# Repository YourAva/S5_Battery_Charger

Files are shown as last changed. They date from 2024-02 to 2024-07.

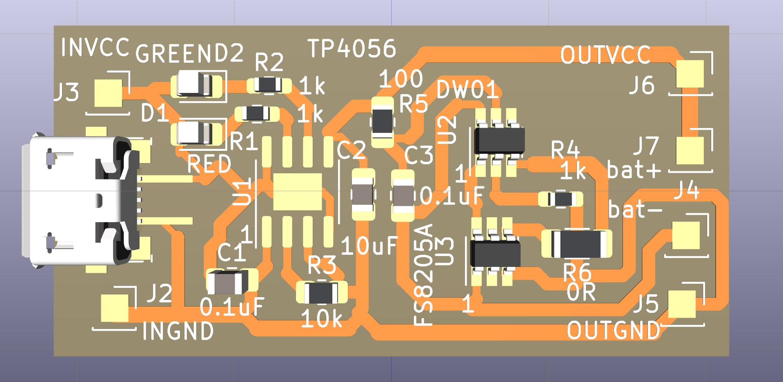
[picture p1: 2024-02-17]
out/tp4056_pcb.jpg

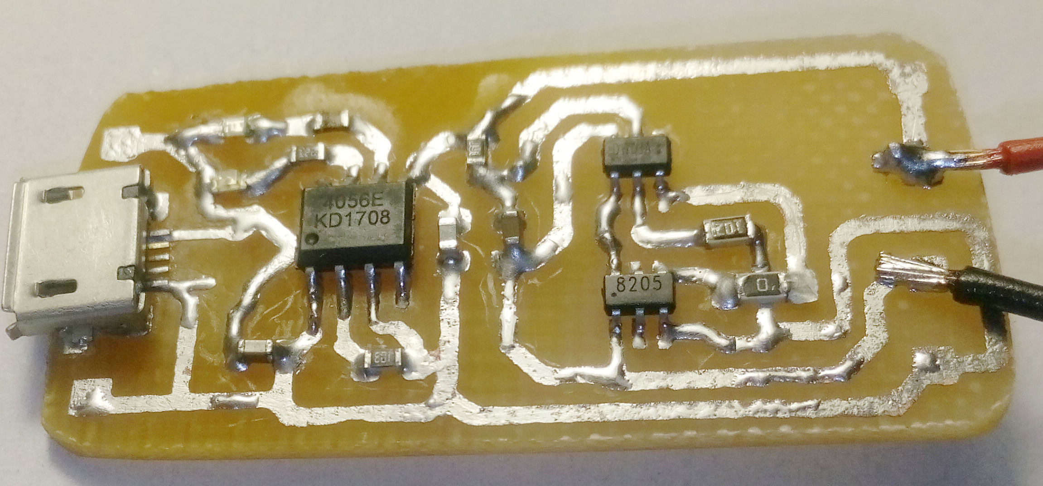
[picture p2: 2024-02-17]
out/tp4056_diy_img2.jpg

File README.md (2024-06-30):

# S5 BATTERY CHARGER

### IMPORTANT

This project is built ontop of another individual's TP4056 board. If you wish to give your respects to the original dev, you can find their github repo that it was pulled from **[here](https://github.com/alltheworld/tp4056)**, any visits to their repo would be greatly appreciated, making sure we all work together is important! >:L

**THE FILE STRUCTURE FOR THIS PROJECT IS DOOKIE RIGHT NOW, I MIGHT FIX IT ONE DAY, BUT AS OF RIGHT NOW IT'S GONE THROUGH 8 DIFFERENT INSTALLS OF WINDOWS AND LINUX AND MULTIPLE KICAD VERSIONS BECAUSE I'M DUMB, LY!**

### Project Overview

This project was made with a pretty simple goal in mind, charging support for the S5 battery, with other options towards charging it and being able to implement it with other circuits, the project provides multiple breakout points so it can adapt to all conditions you'd ever want it to, along with the **SUPERIOR USB-C LINK!!!** ;)

## Credits -- *(thank you all :L )*
- [Original Repo](https://github.com/alltheworld/tp4056)
- [0xArya/@FairywrenTech](https://twitter.com/FairywrenTech)

## Screenshots / Renders







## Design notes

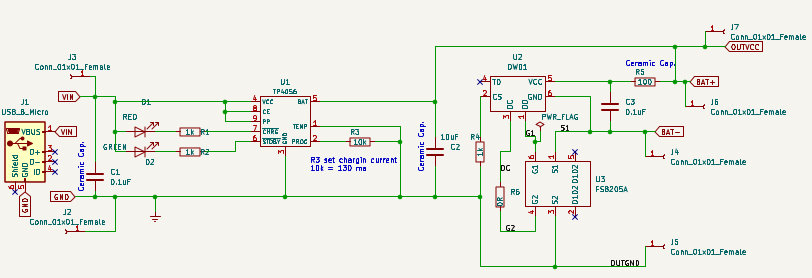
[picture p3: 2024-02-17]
out/tp4056_schematics.jpg

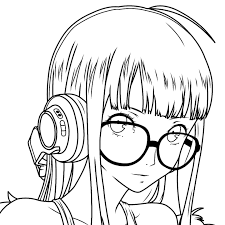
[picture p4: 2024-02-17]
FUtaba.png

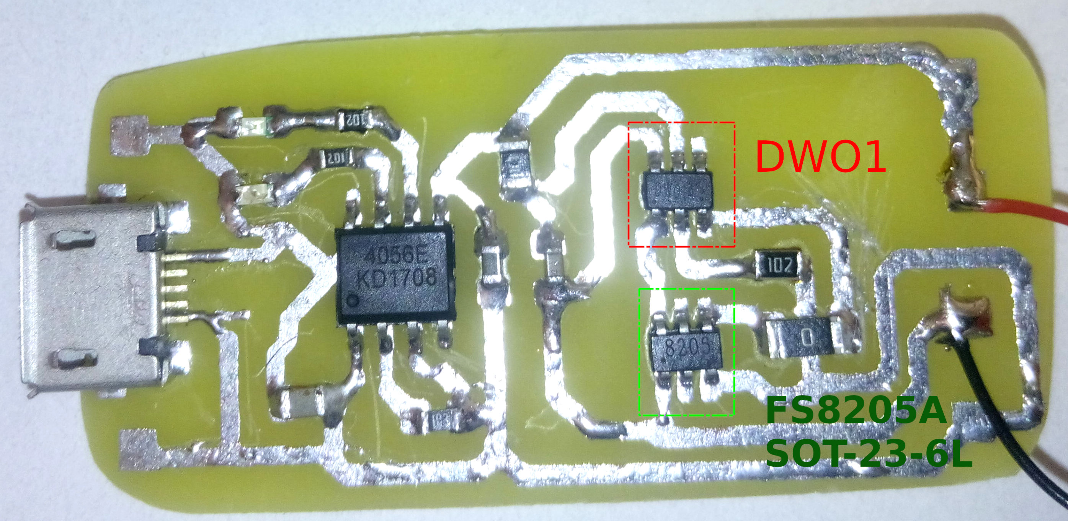
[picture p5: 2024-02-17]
out/tp4056_diy_img1.jpg

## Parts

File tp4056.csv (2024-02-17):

Source: | /data/repo.mbed/tp4056/tp4056_kicad6_base/tp4056.kicad_sch
Date: | Tue 29 Mar 2022 10:57:33 AM EEST
Tool: | Eeschema 6.0.4-6f826c9f35~116~ubuntu20.04.1
Generator: | /usr/share/kicad/plugins/bom_csv_grouped_by_value.py
Component Count: | 21
Individual Components:
Item | Qty | Reference(s) | Value | LibPart | Footprint | Datasheet
 |  | C1 | 0.1uF | Device:C | Capacitor_SMD:C_0805_2012Metric_Pad1.18x1.45mm_HandSolder | ~
 |  | C2 | 10uF | Device:C | Capacitor_SMD:C_0805_2012Metric_Pad1.18x1.45mm_HandSolder | ~
 |  | C3 | 0.1uF | Device:C | Capacitor_SMD:C_0805_2012Metric_Pad1.18x1.45mm_HandSolder | ~
 |  | D1 | LED | Device:LED | LED_SMD:LED_0805_2012Metric_Pad1.15x1.40mm_HandSolder | ~
 |  | D2 | ~ | Device:LED | LED_SMD:LED_0805_2012Metric_Pad1.15x1.40mm_HandSolder | ~
 |  | J1 | USB_B_Micro | Connector:USB_B_Micro | usb_footprint:tp4056_USB_Micro-B_Molex_47346-0001_fix | ~
 |  | J2 | Conn_01x01_Female | Connector:Conn_01x01_Female | Connector_PinSocket_2.54mm:PinSocket_1x01_P2.54mm_Vertical | ~
 |  | J3 | Conn_01x01_Female | Connector:Conn_01x01_Female | Connector_PinSocket_2.54mm:PinSocket_1x01_P2.54mm_Vertical | ~
 |  | J4 | Conn_01x01_Female | Connector:Conn_01x01_Female | Connector_PinSocket_2.54mm:PinSocket_1x01_P2.54mm_Vertical | ~
 |  | J5 | Conn_01x01_Female | Connector:Conn_01x01_Female | Connector_PinSocket_2.54mm:PinSocket_1x01_P2.54mm_Vertical | ~
 |  | J6 | Conn_01x01_Female | Connector:Conn_01x01_Female | Connector_PinSocket_2.54mm:PinSocket_1x01_P2.54mm_Vertical | ~
 |  | J7 | Conn_01x01_Female | Connector:Conn_01x01_Female | Connector_PinSocket_2.54mm:PinSocket_1x01_P2.54mm_Vertical | ~
 |  | R1 | 1k | Device:R | Resistor_SMD:R_0603_1608Metric_Pad0.98x0.95mm_HandSolder | ~
 |  | R2 | 1k | Device:R | Resistor_SMD:R_0603_1608Metric_Pad0.98x0.95mm_HandSolder | ~
 |  | R3 | 10k | Device:R | Resistor_SMD:R_0805_2012Metric_Pad1.20x1.40mm_HandSolder | ~
 |  | R4 | 1k | Device:R | Resistor_SMD:R_0603_1608Metric_Pad0.98x0.95mm_HandSolder | ~
 |  | R5 | 100 | Device:R | Resistor_SMD:R_0805_2012Metric_Pad1.20x1.40mm_HandSolder | ~
 |  | R6 | ZERO | Device:R | Resistor_SMD:R_1206_3216Metric_Pad1.30x1.75mm_HandSolder | ~
 |  | U1 | TP4056 | tp4056:TP4056 | Package_SO:SOIC-8-1EP_3.9x4.9mm_P1.27mm_EP2.29x3mm
 |  | U2 | DW01 | dw01:DW01 | Package_TO_SOT_SMD:SOT-23-6_Handsoldering
 |  | U3 | FS8205A | fs8205:FS8205A | Package_TO_SOT_SMD:SOT-23-6_Handsoldering
Collated Components:
Item | Qty | Reference(s) | Value | LibPart | Footprint | Datasheet
1 | 2 | C1, C3 | 0.1uF | Device:C | Capacitor_SMD:C_0805_2012Metric_Pad1.18x1.45mm_HandSolder | ~
2 | 1 | C2 | 10uF | Device:C | Capacitor_SMD:C_0805_2012Metric_Pad1.18x1.45mm_HandSolder | ~
3 | 1 | D1 | LED | Device:LED | LED_SMD:LED_0805_2012Metric_Pad1.15x1.40mm_HandSolder | ~
4 | 1 | D2 | ~ | Device:LED | LED_SMD:LED_0805_2012Metric_Pad1.15x1.40mm_HandSolder | ~
5 | 1 | J1 | USB_B_Micro | Connector:USB_B_Micro | usb_footprint:tp4056_USB_Micro-B_Molex_47346-0001_fix | ~
6 | 6 | J2, J3, J4, J5, J6, J7 | Conn_01x01_Female | Connector:Conn_01x01_Female | Connector_PinSocket_2.54mm:PinSocket_1x01_P2.54mm_Vertical | ~
7 | 3 | R1, R2, R4 | 1k | Device:R | Resistor_SMD:R_0603_1608Metric_Pad0.98x0.95mm_HandSolder | ~
8 | 1 | R3 | 10k | Device:R | Resistor_SMD:R_0805_2012Metric_Pad1.20x1.40mm_HandSolder | ~
9 | 1 | R5 | 100 | Device:R | Resistor_SMD:R_0805_2012Metric_Pad1.20x1.40mm_HandSolder | ~
10 | 1 | R6 | ZERO | Device:R | Resistor_SMD:R_1206_3216Metric_Pad1.30x1.75mm_HandSolder | ~
11 | 1 | U1 | TP4056 | tp4056:TP4056 | Package_SO:SOIC-8-1EP_3.9x4.9mm_P1.27mm_EP2.29x3mm
12 | 1 | U2 | DW01 | dw01:DW01 | Package_TO_SOT_SMD:SOT-23-6_Handsoldering
13 | 1 | U3 | FS8205A | fs8205:FS8205A | Package_TO_SOT_SMD:SOT-23-6_Handsoldering

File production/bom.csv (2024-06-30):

Designator | Footprint | Quantity | Value | LCSC Part #
C1, C3 | 0603 | 2 | 0.1uF
C2 | 0603 | 1 | 10uF
D1 | 0805 | 1 | RED
D2 | 0805 | 1 | GREEN
J1 | PinHeader_1x01_P2.54mm_Vertical | 1 | Conn_01x01_Pin
J2, J3, J4, J5, J7 | PinSocket_1x01_P2.54mm_Vertical | 5 | Conn_01x01_Female
J6 | CONN-SMD_BC-4-3PD | 1 | Conn_01x03_MountingPin
J8 | USB_C_Receptacle_HRO_TYPE-C-31-M-12 | 1 | USB_C_Receptacle_USB2.0
R1, R2, R4 | 0603 | 3 | 1k
R10 | 0805 | 1 | 1k
R3, R8, R9 | 0603 | 3 | 10k
R5 | 0603 | 1 | 100
R6, R7 | 0603 | 2 | 5.1k
U1 | SOIC-8-1EP_3.9x4.9mm_P1.27mm_EP2.29x3mm | 1 | TP4056
U2 | SOT-23-6_Handsoldering | 1 | DW01
U3 | SOT-23-6_Handsoldering | 1 | FS8205A

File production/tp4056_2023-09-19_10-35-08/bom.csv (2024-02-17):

Designator | Footprint | Quantity | Value | LCSC Part #
C1, C3 | 0805 | 2 | 0.1uF
C2 | 0805 | 1 | 10uF
D1 | 0805 | 1 | RED
D2 | 0805 | 1 | GREEN
J1, J2, J3, J4, J5, J7, J9 | PinSocket_1x01_P2.54mm_Vertical | 7 | Conn_01x01_Female
J6 | CONN-SMD_BC-4-3PD | 1 | Conn_01x03_MountingPin
J8 | USB_C_Receptacle_HRO_TYPE-C-31-M-12 | 1 | USB_C_Receptacle_USB2.0
R1, R2, R4 | 0603 | 3 | 1k
R3 | 0805 | 1 | 10k
R5 | 0805 | 1 | 100
R6, R7 | 0603 | 2 | 5.1k
U1 | SOIC-8-1EP_3.9x4.9mm_P1.27mm_EP2.29x3mm | 1 | TP4056
U2 | SOT-23-6_Handsoldering | 1 | DW01
U3 | SOT-23-6_Handsoldering | 1 | FS8205A

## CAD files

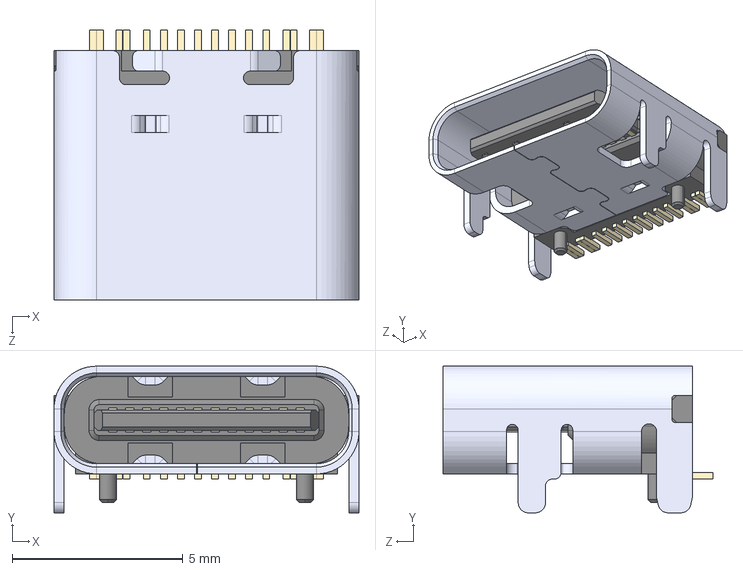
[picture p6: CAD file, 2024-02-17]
TYPE-C-31-M-12--3DModel-STEP-56544.STEP
8.94 x 4.30 x 7.90 mm

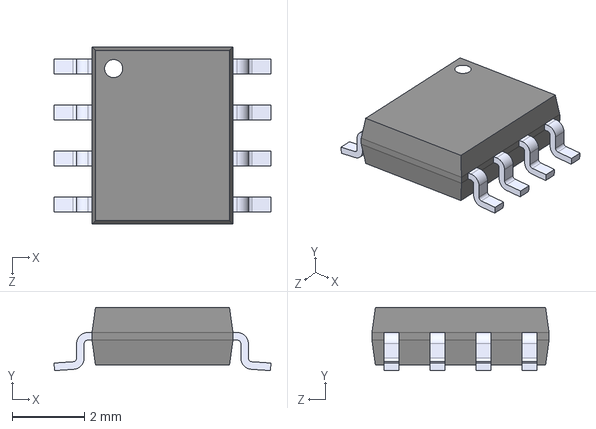
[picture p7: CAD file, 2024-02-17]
TP4056--3DModel-STEP-56544.STEP
6.00 x 1.75 x 4.90 mm

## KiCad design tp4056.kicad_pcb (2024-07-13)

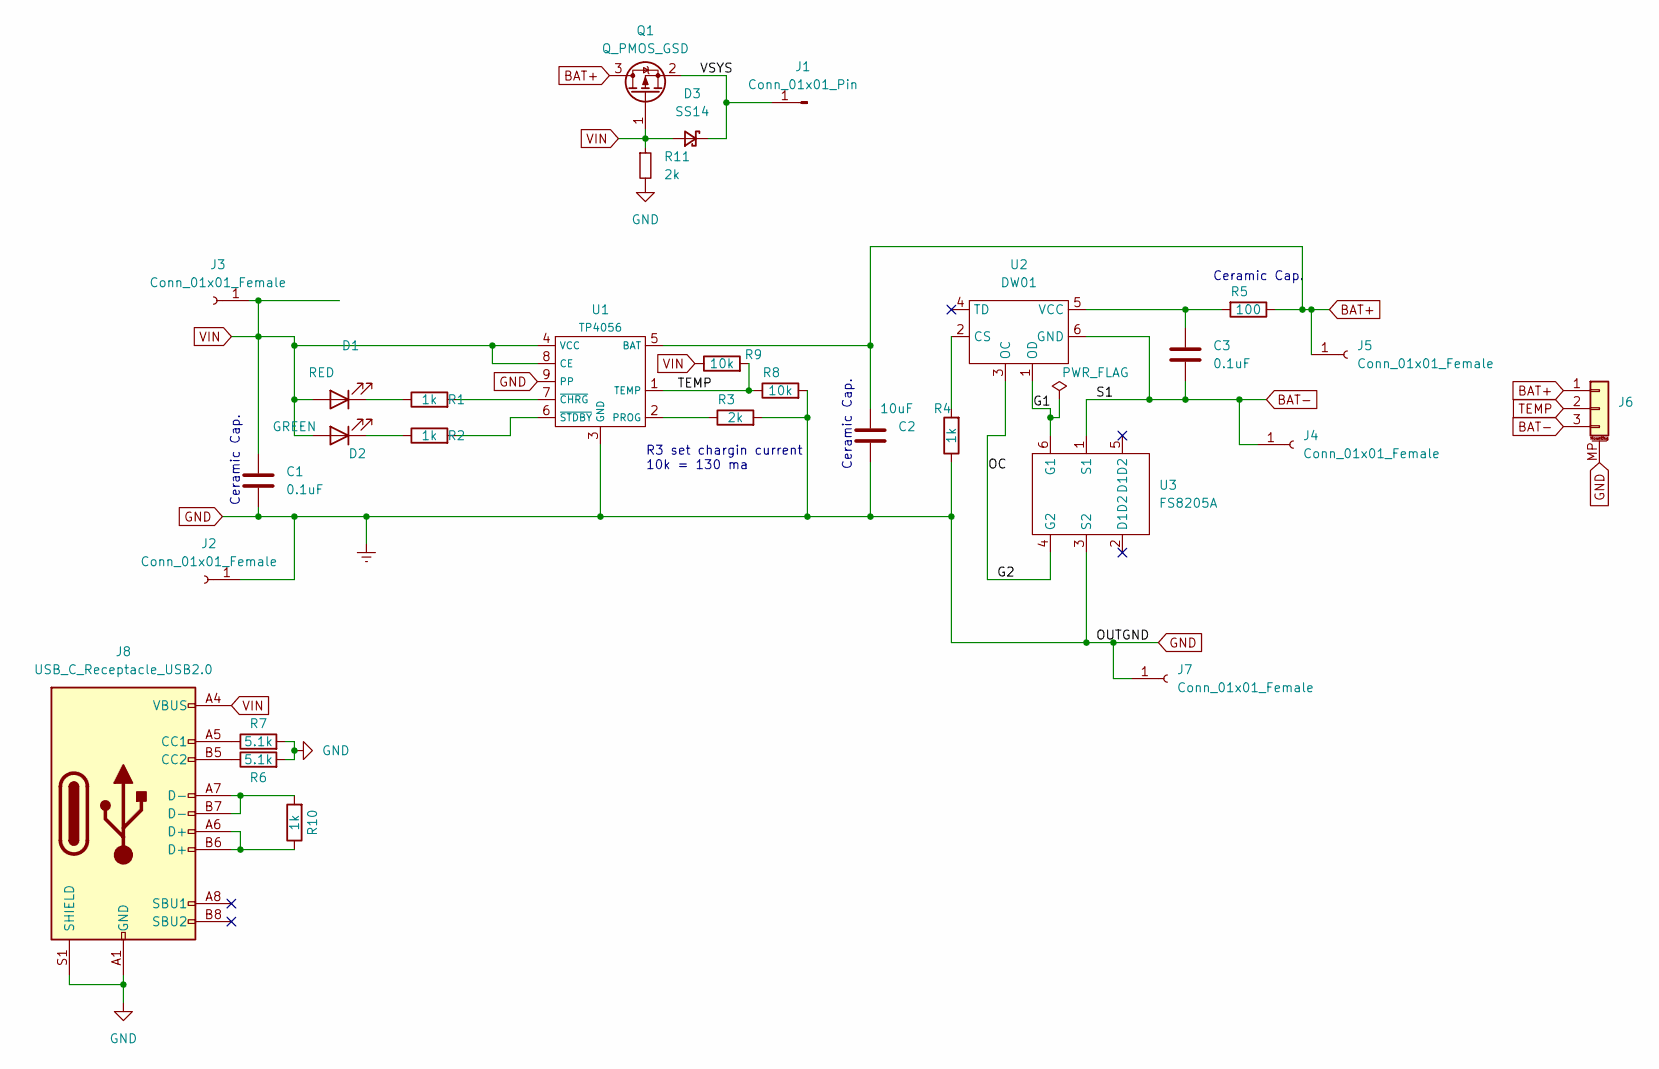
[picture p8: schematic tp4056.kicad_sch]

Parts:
C1, C3: 0.1uF; C_0603_1608Metric_Pad1.08x0.95mm_HandSolder
C2: 10uF; C_0603_1608Metric_Pad1.08x0.95mm_HandSolder
D1: RED; LED_0805_2012Metric_Pad1.15x1.40mm_HandSolder
D2: GREEN; LED_0805_2012Metric_Pad1.15x1.40mm_HandSolder
D3: SS14; D_SMA
J1: Conn_01x01_Pin; PinSocket_1x01_P2.54mm_Vertical
J2, J3, J4, J5, J7: Conn_01x01_Female; PinSocket_1x01_P2.54mm_Vertical
J6: Conn_01x03_MountingPin; CONN-SMD_BC-4-3PD
J8: USB_C_Receptacle_USB2.0; USB_C_Receptacle_HRO_TYPE-C-31-M-12
Q1: Q_PMOS_GSD; SOT-23
R1, R2, R4: 1k; R_0603_1608Metric_Pad0.98x0.95mm_HandSolder
R3, R11: 2k; R_0603_1608Metric_Pad0.98x0.95mm_HandSolder
R5: 100; R_0603_1608Metric_Pad0.98x0.95mm_HandSolder
R6, R7: 5.1k; R_0603_1608Metric_Pad0.98x0.95mm_HandSolder
R8, R9: 10k; R_0603_1608Metric_Pad0.98x0.95mm_HandSolder
R10: 1k; R_0805_2012Metric_Pad1.20x1.40mm_HandSolder
U1: TP4056; SOIC-8-1EP_3.9x4.9mm_P1.27mm_EP2.29x3mm
U2: DW01; SOT-23-6_Handsoldering
U3: FS8205A; SOT-23-6_Handsoldering

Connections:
/G1: U2.1 (OD), U3.6 (G1)
/G2: U2.3 (OC), U3.4 (G2)
/VSYS: D3.1 (K), J1.1, Q1.2 (S)
BAT+: C2.1, J5.1, J6.1, Q1.3 (D), R5.1, U1.5 (BAT)
BAT-: C3.2, J4.1, J6.3, U2.6 (GND), U3.1 (S1)
GND: C1.2, C2.2, J2.1, J6.MP (MountPin), J7.1, J8.A1 (GND), J8.A12 (GND), J8.B1 (GND), J8.B12 (GND), J8.S1 (SHIELD), R3.2, R4.1, R6.2, R7.2, R8.2, R11.2, U1.3 (GND), U1.9 (PP), U3.3 (S2)
unnamed: D1.1 (K), R1.1
unnamed: D2.1 (K), R2.1
unnamed: J8.A5 (CC1), R7.1
unnamed: J8.B5 (CC2), R6.1
unnamed: J8.A6 (D+), J8.B6 (D+), R10.1
unnamed: J8.A7 (D-), J8.B7 (D-), R10.2
unnamed: R3.1, U1.2 (PROG)
unnamed: R1.2, U1.7 (~CHRG)
unnamed: R2.2, U1.6 (~STDBY)
unnamed: R4.2, U2.2 (CS)
unnamed: C3.1, R5.2, U2.5 (VCC)
TEMP: J6.2, R8.1, R9.2, U1.1 (TEMP)
VIN: C1.1, D1.2 (A), D2.2 (A), D3.2 (A), J3.1, J8.A4 (VBUS), J8.A9 (VBUS), J8.B4 (VBUS), J8.B9 (VBUS), Q1.1 (G), R9.1, R11.1, U1.4 (VCC), U1.8 (CE)

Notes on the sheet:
Ceramic Cap.
R3 set chargin current 10k = 130 ma

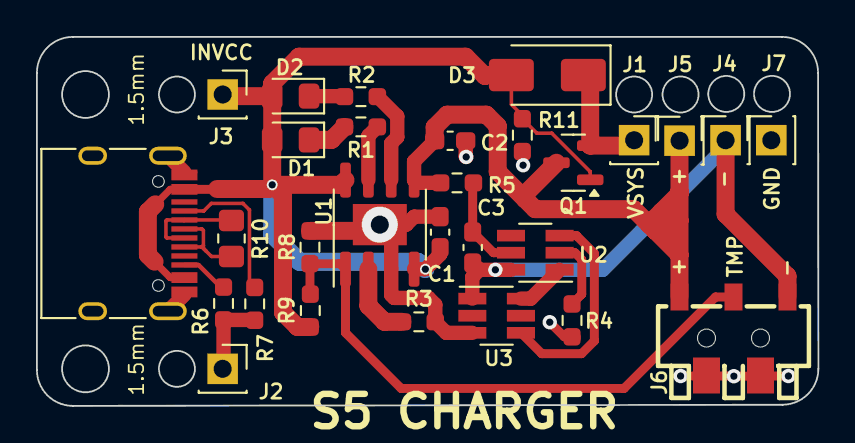
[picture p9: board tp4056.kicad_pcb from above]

Board: 2 copper layers, 43.4 x 20.5 mm, 29 parts (0 on the bottom side), 19 nets.

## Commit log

2024-02-17 Initial Push
    [TP4056--3DModel-STEP-56544.STEP, TYPE-C-31-M-12--3DModel-STEP-56544.STEP, bom.csv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]
2024-03-08 More Additions
    [bom.csv, designators.csv, positions.csv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]
2024-06-30 Final Project Push
    [bom.csv, designators.csv, positions.csv]
2024-07-13 actual changes: moved components around to free some space, added power path outputting on J1, enlarged via under the package to make soldering-iron rework possible, made PROG resistor 0805; designat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
    [tp4056.kicad_pcb, tp4056.kicad_sch]
